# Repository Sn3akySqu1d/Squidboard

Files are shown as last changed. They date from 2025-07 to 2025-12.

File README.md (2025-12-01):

Squidboard is a tilted, 60% keyboard with a rotary encoder and oled display. It has a pomodoro timer, animations and more.

Funded by Hack Club's Highway program
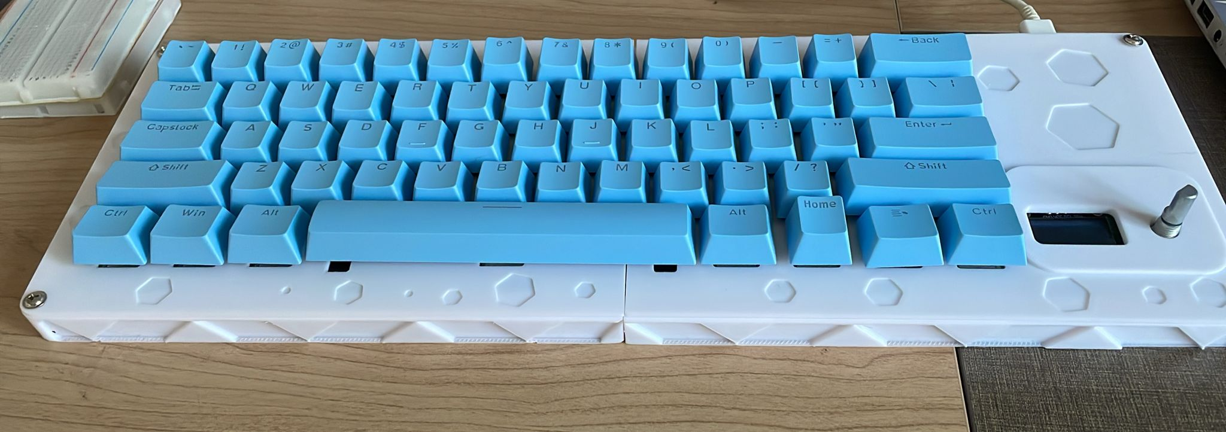
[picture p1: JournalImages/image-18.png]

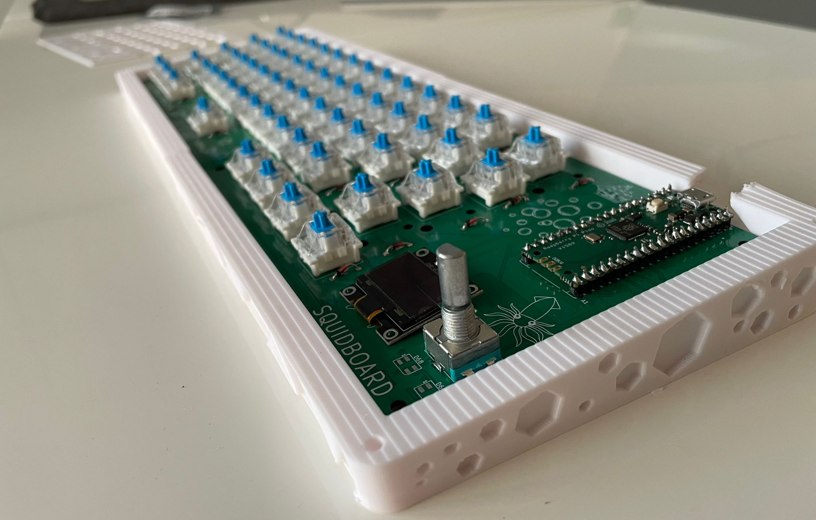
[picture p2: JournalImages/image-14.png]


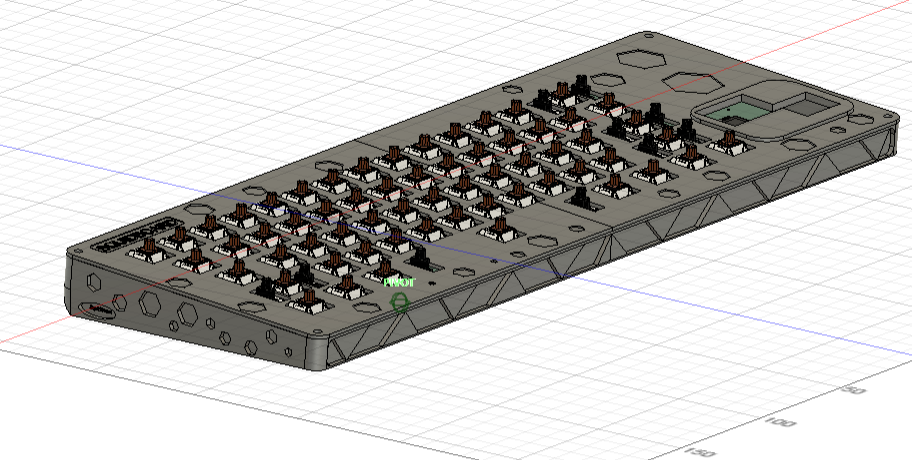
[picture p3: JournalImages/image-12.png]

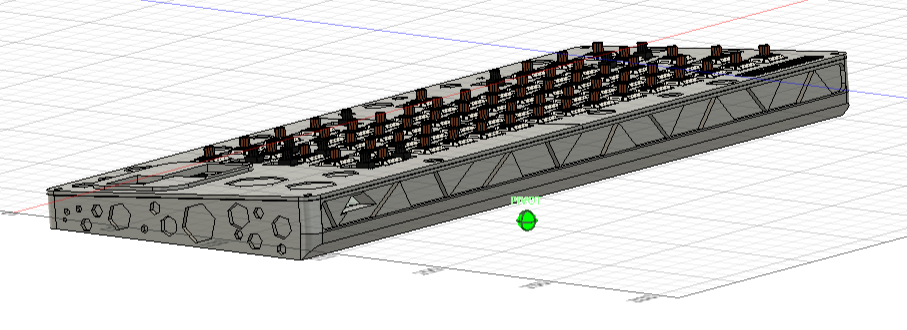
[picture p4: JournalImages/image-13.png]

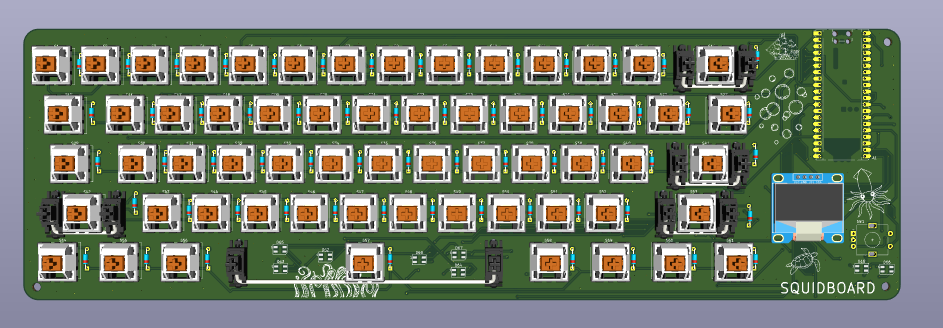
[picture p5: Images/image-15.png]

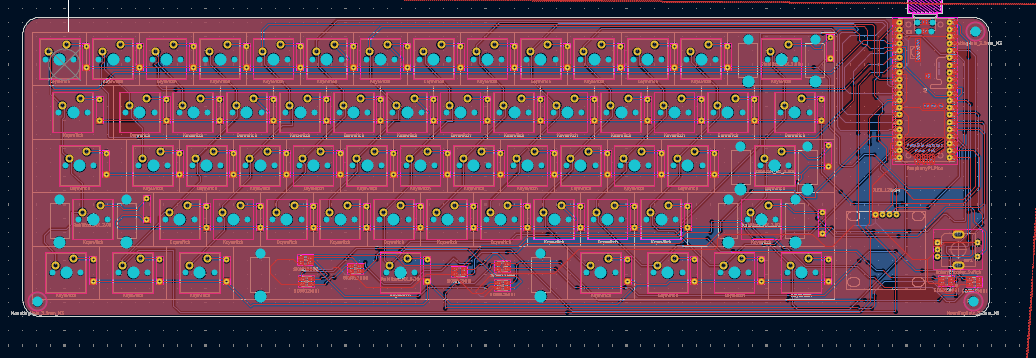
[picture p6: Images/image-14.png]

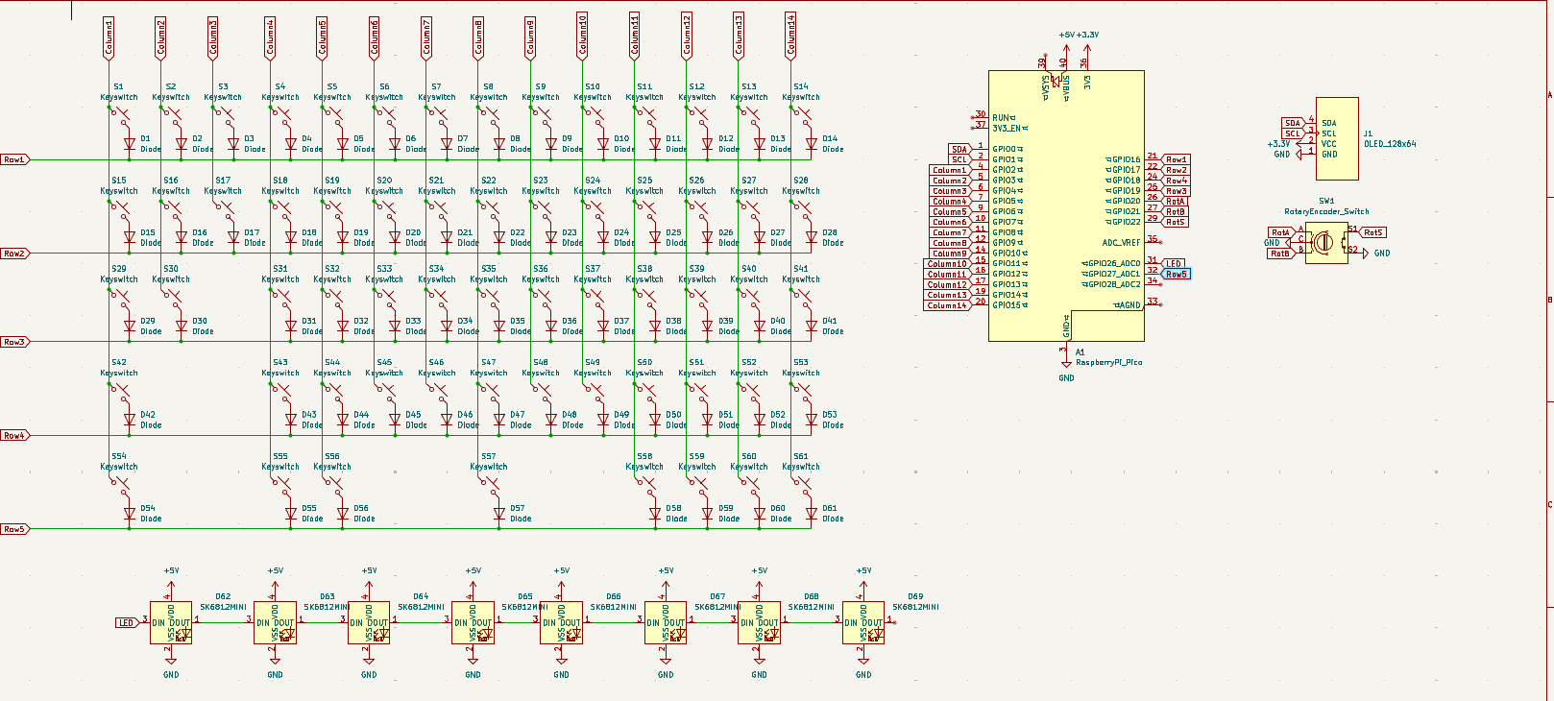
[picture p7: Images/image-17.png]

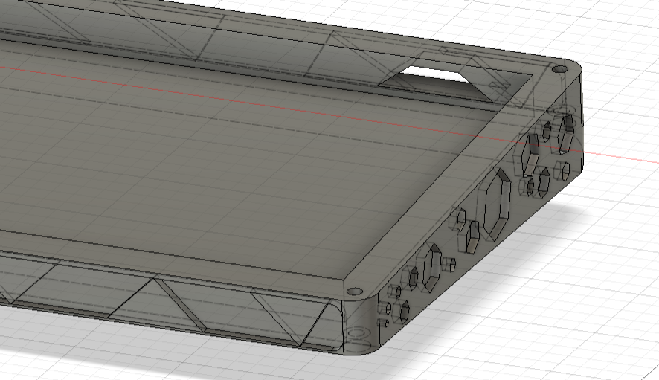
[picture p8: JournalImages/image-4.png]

| Component | Link | Price (usd) |
|---|---|---|
| Raspberry pi pico | https://www.aliexpress.us/item/1005007393927221.html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 | 7.67 |
| OLED display | https://www.aliexpress.com/item/1005006262908701.html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 | 3.83 |
| MX Switches | https://www.aliexpress.us/item/1005004285423123.html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 | 8.48 |
| diodes do-35 | https://www.aliexpress.us/item/4000142272546.html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 | 1.67 |
| keycaps | https://www.aliexpress.us/item/1005008144804720.html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 | 8.40 |
| rotary encoder | https://www.aliexpress.us/item/1005003642889774.html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 | 3.74 |
| keyboard stabilizers  | https://www.aliexpress.us/item/1005006528731543.html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 | 8.25 |
| LEDs | https://www.aliexpress.us/item/1005006473087141.html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 | 7.15 |
| 3d prints | my printer | 0.00 |
| PCB | JLCPCB | 32.84 |
| **Total** | | **82.03** |

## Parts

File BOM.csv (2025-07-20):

Component | Link | Price (usd)
Raspberry pi pico | https://www.aliexpress.us/item/1005007393927221.html?src=google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 | 7.67
OLED display | https://www.aliexpress.com/item/1005006262908701.html?src=google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 | 3.83
MX Switches | https://www.aliexpress.us/item/1005004285423123.html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 | 8.48
diodes do-35 | https://www.aliexpress.us/item/4000142272546.html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 | 1.67
keycaps | https://www.aliexpress.us/item/1005008144804720.html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 | 8.40
rotary encoder | https://www.aliexpress.us/item/1005003642889774.html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 | 3.74
keyboard stabilizers | https://www.aliexpress.us/item/1005006528731543.html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 | 8.25
LEDs | https://www.aliexpress.us/item/1005006473087141.html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 | 7.15
3d prints | my printer | 0
PCB | JLCPCB | 32.84

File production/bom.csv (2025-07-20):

Designator | Footprint | Quantity | Value | LCSC Part #
A1 | RaspberryPi_Pico_Common_Unspecified | 1 | RaspberryPi_Pico
D1, D10, D11, D12, D13, D14, D15, D16, D17, D18, D19, D2, D20, D21, D22, D23, D24, D25, D26, D27, D28, D29, D3, D30, D31, D32, D33, D34, D35, D36, D37, D38, D39, D4, D40, D41, D42, D43, D44, D45, D46, D47, D48, D49, D5, D50, D51, D52, D53, D54, D55, D56, D57, D58, D59, D6, D60, D61, D7, D8, D9 | Diode_DO-35 | 61 | Diode
D62, D63, D64, D65, D66, D67, D68, D69 | LED_SK6812MINI_PLCC4_3.5x3.5mm_P1.75mm | 8 | SK6812MINI
J1 | OLED_128x64 | 1 | OLED_128x64
S1, S10, S11, S12, S13, S16, S17, S18, S19, S2, S20, S21, S22, S23, S24, S25, S26, S27, S3, S30, S31, S32, S33, S34, S35, S36, S37, S38, S39, S4, S40, S43, S44, S45, S46, S47, S48, S49, S5, S50, S51, S52, S6, S7, S8, S9 | MX_PCB_1.00u | 46 | Keyswitch
S14 | MX_PCB_2.00u | 1 | Keyswitch
S15, S28 | MX_PCB_1.50u | 2 | Keyswitch
S29 | MX_PCB_1.75u | 1 | Keyswitch
S41, S42 | MX_PCB_2.25u | 2 | Keyswitch
S53 | MX_PCB_2.75u | 1 | Keyswitch
S54, S55, S56, S58, S59, S60, S61 | MX_PCB_1.25u | 7 | Keyswitch
S57 | MX_PCB_6.25u | 1 | Keyswitch
SW1 | RotaryEncoder_Alps_EC11E-Switch_Vertical_H20mm | 1 | RotaryEncoder_Switch

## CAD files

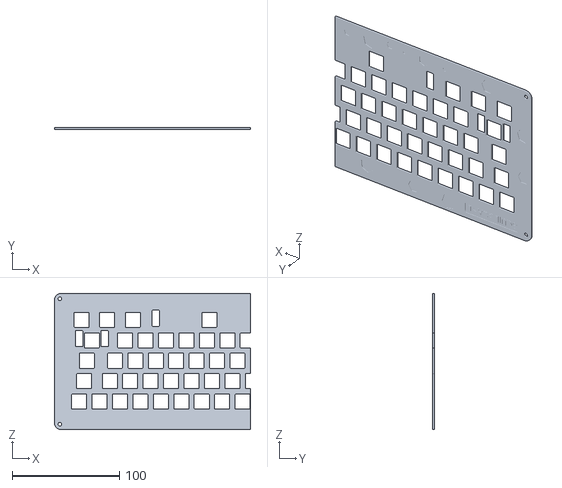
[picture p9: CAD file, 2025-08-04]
CAD/topLeftUpdated.stl
182.6 x 1.50 x 126.8

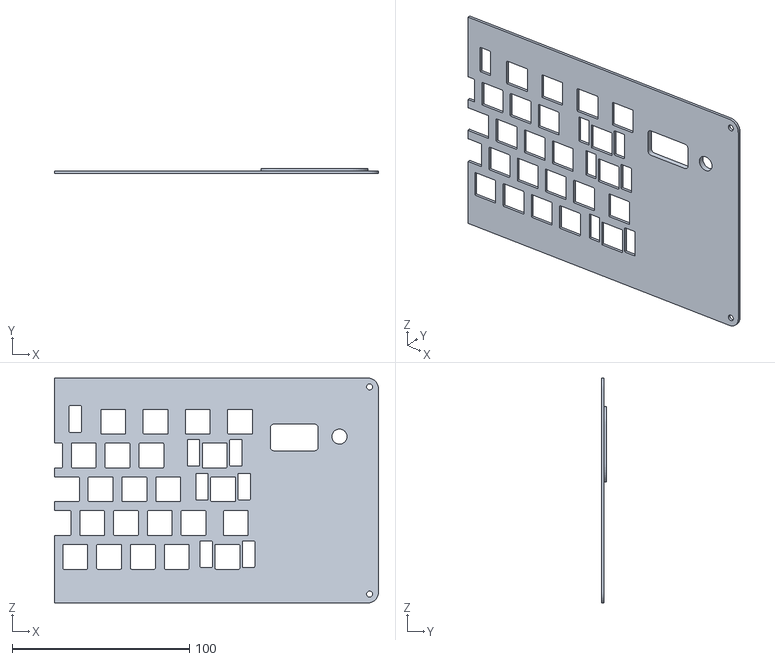
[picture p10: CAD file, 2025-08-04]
CAD/topRightUpdated.stl
182.6 x 3.00 x 126.8

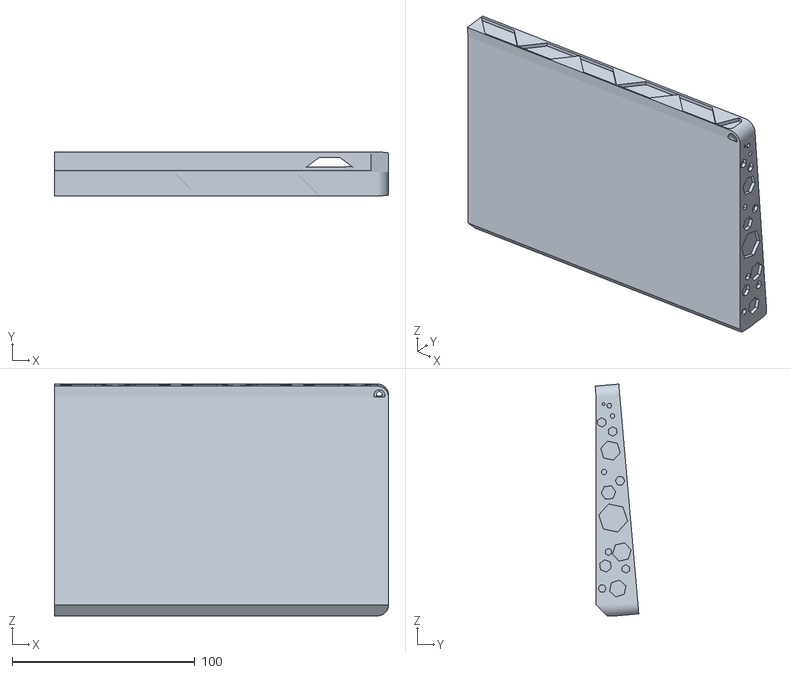
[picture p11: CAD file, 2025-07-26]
CAD/bottom right.stl
183.0 x 24.0 x 127.1

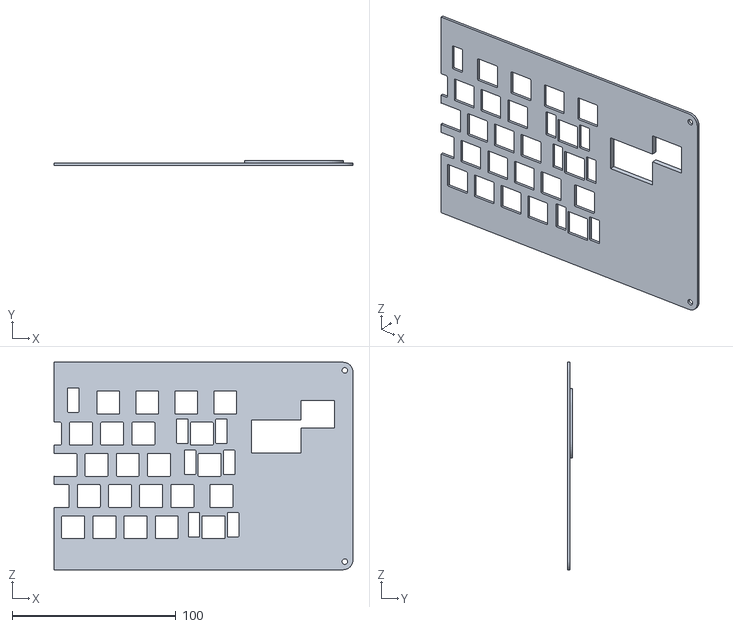
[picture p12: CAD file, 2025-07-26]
CAD/top right.stl
182.6 x 3.00 x 126.8

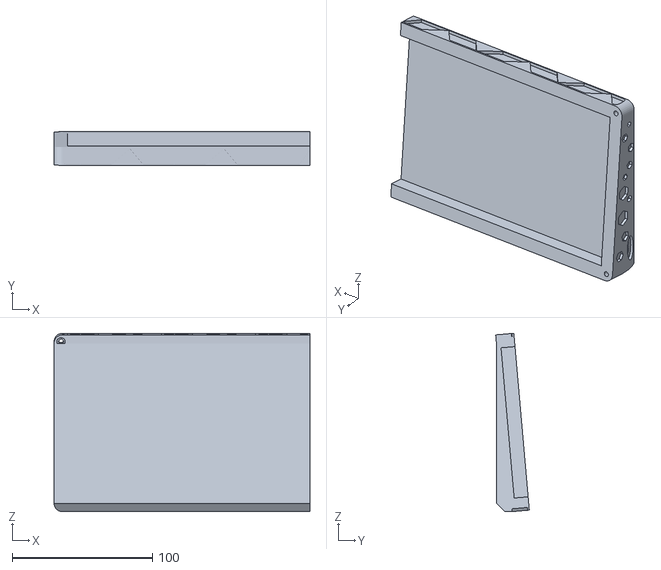
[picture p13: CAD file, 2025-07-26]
CAD/bottom left.stl
182.3 x 24.0 x 127.1

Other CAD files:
CAD/top left.stl

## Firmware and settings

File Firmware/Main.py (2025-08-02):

import board
import busio
import time
import adafruit_ssd1306
import digitalio
from kmk.kmk_keyboard import KMKKeyboard
from kmk.keys import KC
from kmk.scanners import DiodeOrientation

print("Starting code")

i2c = busio.I2C(scl=board.GP1, sda=board.GP0)
oled = adafruit_ssd1306.SSD1306_I2C(128, 64, i2c)

encoder_pin_a = digitalio.DigitalInOut(board.GP20)
encoder_pin_a.direction = digitalio.Direction.INPUT
encoder_pin_a.pull = digitalio.Pull.UP

encoder_pin_b = digitalio.DigitalInOut(board.GP21)
encoder_pin_b.direction = digitalio.Direction.INPUT
encoder_pin_b.pull = digitalio.Pull.UP

encoder_button = digitalio.DigitalInOut(board.GP22)
encoder_button.direction = digitalio.Direction.INPUT
encoder_button.pull = digitalio.Pull.UP

keyboard = KMKKeyboard()
keyboard.col_pins = (board.GP2, board.GP3, board.GP4, board.GP5, board.GP6, board.GP7,
                     board.GP8, board.GP9, board.GP10, board.GP11, board.GP12, board.GP13,
                     board.GP14, board.GP15)
keyboard.row_pins = (board.GP16, board.GP17, board.GP19, board.GP18, board.GP27)
keyboard.diode_orientation = DiodeOrientation.COL2ROW
keyboard.keymap = [[
    KC.GRAVE, KC.N1, KC.N2, KC.N3, KC.N4, KC.N5, KC.N6, KC.N7,
    KC.N8, KC.N9, KC.N0, KC.MINUS, KC.EQUAL, KC.BACKSPACE,

    KC.TAB, KC.Q, KC.W, KC.E, KC.R, KC.T, KC.Y, KC.U,
    KC.I, KC.O, KC.P, KC.LBRACKET, KC.RBRACKET, KC.BSLASH,

    KC.CAPS_LOCK, KC.A, KC.NO, KC.S, KC.D, KC.F, KC.G, KC.H,
    KC.J, KC.K, KC.L, KC.SEMICOLON, KC.QUOTE, KC.ENTER,

    KC.LSHIFT, KC.NO, KC.NO, KC.Z, KC.X, KC.C, KC.V, KC.B,
    KC.N, KC.M, KC.COMMA, KC.DOT, KC.SLASH, KC.RSHIFT,

    KC.LCONTROL, KC.NO, KC.NO, KC.LGUI, KC.LALT, KC.NO, KC.NO, KC.SPACE,
    KC.NO, KC.NO, KC.RALT, KC.RGUI, KC.APPLICATION, KC.RCONTROL,
]]


class OledMenu:
    def __init__(self, kb):
        self.keyboard = kb
        self.menu_items = ["Animation", "Timer", "Session Time", "Pomodoro Mode"]
        self.selected_index = 0
        self.current_screen = "menu"

        self.timer_setting = 60
        self.timer_running = False
        self.timer_start_time = None
        self.timer_state = "set"
        self.timer_options = ["Start Timer", "Back"]
        self.timer_option_index = 0

        self.session_start = time.monotonic()

        self.pomodoro_state = "idle"
        self.pomodoro_start = None
        self.pomodoro_count = 0
        self.animation_frames = [
        ["  o   o   o  ", " /|\\ /|\\ /|\\ ", " / \\ / \\ / \\ "],
        [" \\o/ o   o/ ", "  |  /|\\ |\\  ", " / \\ / \\ / \\ "],
        ["  o/ \\o/ \\o ", " /|   |   |\\ ", " / \\ / \\ / \\ "],
        [" \\o   o   o/", "  |\\ /|\\ /|  ", " / \\ / \\ / \\ "],
        ]



        self.animation_frame = 0
        self._last_anim_time = time.monotonic()

        self.last_a = encoder_pin_a.value
        self.last_b = encoder_pin_b.value
        self.button_last = encoder_button.value
        self.encoder_delta = 0
        self.button_pressed = False

    def during_bootup(self, sandbox): pass
    def before_hid_send(self, sandbox): pass
    def after_hid_send(self, sandbox): pass
    def before_matrix_scan(self, sandbox): pass
    def deinit(self, sandbox): pass

    def after_matrix_scan(self, sandbox):
        now = time.monotonic()

        a = encoder_pin_a.value
        b = encoder_pin_b.value
        if a != self.last_a:
            if b != a:
                self.encoder_delta += 1
        self.last_a = a
        self.last_b = b

        button = encoder_button.value
        if not button and self.button_last:
            self.button_pressed = True
        self.button_last = button

        if self.current_screen == "menu":
            if self.encoder_delta > 0:
                self.selected_index = (self.selected_index + 1) % len(self.menu_items)
                self.encoder_delta = 0
            if self.button_pressed:
                self.button_pressed = False
                selected = self.menu_items[self.selected_index]
                self.current_screen = selected.lower().replace(" ", "_")
                if self.current_screen == "timer":
                    self.timer_state = "set"
                elif self.current_screen == "pomodoro_mode":
                    self.pomodoro_state = "work"
                    self.pomodoro_start = now

        elif self.current_screen == "timer":
            if self.timer_state == "set":
                if self.encoder_delta > 0:
                    self.timer_setting += 10
                    self.encoder_delta = 0
                if self.button_pressed:
                    self.button_pressed = False
                    self.timer_state = "start_or_back"
            elif self.timer_state == "start_or_back":
                if self.encoder_delta > 0:
                    self.timer_option_index = (self.timer_option_index + 1) % len(self.timer_options)
                    self.encoder_delta = 0
                if self.button_pressed:
                    self.button_pressed = False
                    if self.timer_option_index == 0:
                        self.timer_running = True
                        self.timer_start_time = now
                        self.timer_state = "running"
                    else:
                        self.current_screen = "menu"
            elif self.timer_state == "running":
                if self.button_pressed:
                    self.button_pressed = False
                    self.timer_running = False
                    self.timer_state = "set"
                    self.current_screen = "menu"

        elif self.current_screen == "pomodoro_mode":
            if self.button_pressed:
                self.button_pressed = False
                self.pomodoro_state = "idle"
                self.current_screen = "menu"
            else:
                elapsed = int(now - self.pomodoro_start)
                if self.pomodoro_state == "work" and elapsed >= 25 * 60:
                    self.pomodoro_state = "break"
                    self.pomodoro_start = now
                elif self.pomodoro_state == "break" and elapsed >= 5 * 60:
                    self.pomodoro_state = "work"
                    self.pomodoro_start = now
                    self.pomodoro_count += 1

        elif self.current_screen in ["animation", "session_time"]:
            if self.button_pressed:
                self.button_pressed = False
                self.current_screen = "menu"

        oled.fill(0)

        if self.current_screen == "menu":
            oled.text("Main Menu:", 0, 0, 1)
            for i, item in enumerate(self.menu_items):
                prefix = ">" if i == self.selected_index else " "
                oled.text(f"{prefix} {item}", 0, 12 + i * 12, 1)

        elif self.current_screen == "animation":
            frame = self.animation_frames[self.animation_frame]
            for i, line in enumerate(frame):
                oled.text(line, 0, i * 12, 1)
            if now - self._last_anim_time > 0.4:
                self.animation_frame = (self.animation_frame + 1) % len(self.animation_frames)
                self._last_anim_time = now
            oled.text("Press to return", 0, 56, 1)

        elif self.current_screen == "timer":
            if self.timer_state == "set":
                oled.text("Set Timer (sec):", 0, 0, 1)
                oled.text(f"{self.timer_setting}", 0, 24, 1)
                oled.text("Press to confirm", 0, 56, 1)
            elif self.timer_state == "start_or_back":
                oled.text("Timer Options:", 0, 0, 1)
                for i, item in enumerate(self.timer_options):
                    prefix = ">" if i == self.timer_option_index else " "
                    oled.text(f"{prefix} {item}", 0, 12 + i * 12, 1)
            elif self.timer_state == "running":
                elapsed = int(now - self.timer_start_time)
                remaining = self.timer_setting - elapsed
                if remaining <= 0:
                    oled.text("Time's up!", 0, 24, 1)
                    self.timer_running = False
                    self.timer_state = "set"
                    self.current_screen = "menu"
                else:
                    oled.text("Timer Running:", 0, 0, 1)
                    oled.text(f"{remaining} sec", 0, 24, 1)
                    oled.text("Press to cancel", 0, 56, 1)

        elif self.current_screen == "session_time":
            elapsed = int(now - self.session_start)
            h, m, s = elapsed // 3600, (elapsed % 3600) // 60, elapsed % 60
            oled.text("Session Time:", 0, 0, 1)
            oled.text(f"{h:02}:{m:02}:{s:02}", 0, 24, 1)
            oled.text("Press to return", 0, 56, 1)

        elif self.current_screen == "pomodoro_mode":
            oled.text("Pomodoro Mode:", 0, 0, 1)
            state = "Work" if self.pomodoro_state == "work" else "Break"
            oled.text(f"{state} time", 0, 16, 1)
            elapsed = int(now - self.pomodoro_start)
            total = 25 * 60 if self.pomodoro_state == "work" else 5 * 60
            remaining = total - elapsed
            if remaining < 0:
                remaining = 0
            m, s = divmod(remaining, 60)
            oled.text(f"{m:02}:{s:02}", 0, 32, 1)
            oled.text(f"Pomodoros: {self.pomodoro_count}", 0, 48, 1)
            oled.text("Press to return", 0, 56, 1)

        oled.show()
        self.encoder_delta = 0


oled_menu = OledMenu(keyboard)
keyboard.extensions.append(oled_menu)

print("Starting keyboard loop")
keyboard.go()

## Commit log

2025-07-20 Upload Project
    [BOM.csv, Mechboard.kicad_sch, bom.csv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]
2025-07-20 folder restructure
    [bom.csv, designators.csv, positions.csv]
2025-07-23 uploaded case step file
    [bom.csv, designators.csv, full case.step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]
2025-07-26 updated case
    [bottom left.stl, bottom right.stl, case.3mf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]
2025-07-26 upsated case
